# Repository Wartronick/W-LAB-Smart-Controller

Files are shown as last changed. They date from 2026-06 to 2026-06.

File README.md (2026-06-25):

# W-LAB Smart Controller ⚡

A fully integrated, 3D-printed, open-source smart lab automation controller based on the ESP32.

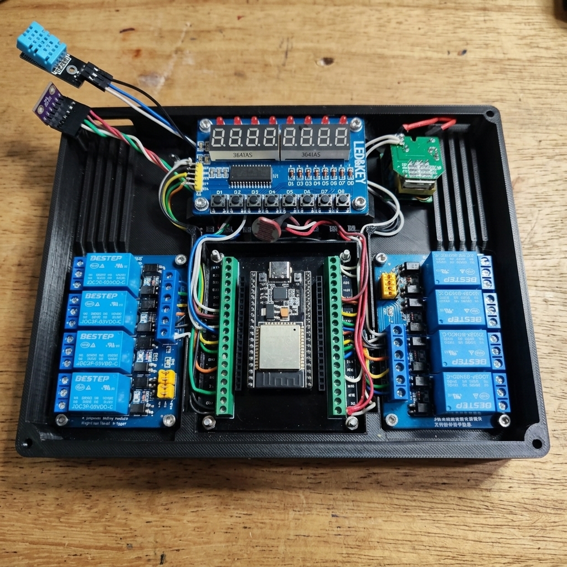
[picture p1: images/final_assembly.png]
Final Assembly


This project transforms an ESP32 into a central command hub for an automation lab (or any workshop), bringing physical controls, sensor fusion, and cloud capabilities into a single beautifully 3D-printed case.

## 📱 Cloud, UI & Voice Control

### ESP RainMaker App
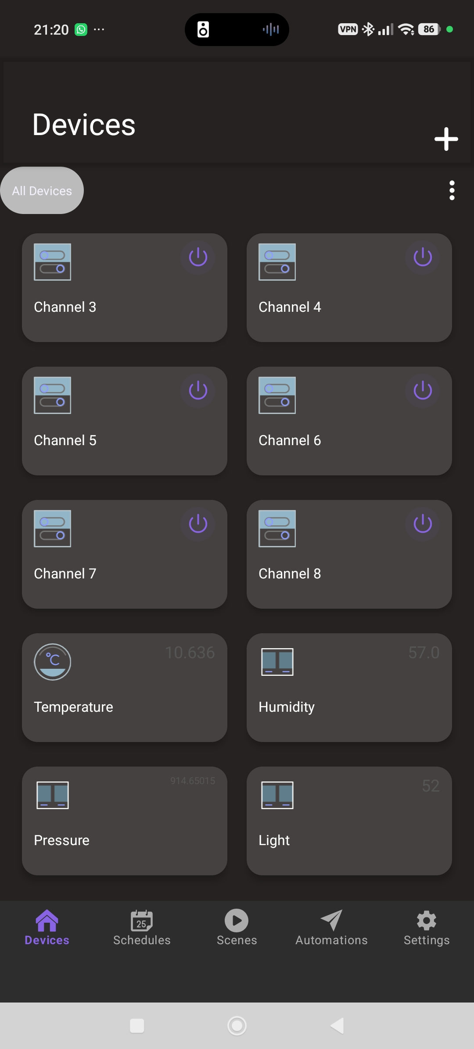
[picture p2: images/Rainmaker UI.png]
RainMaker UI

The system leverages ESP RainMaker for an instant, out-of-the-box mobile dashboard without any backend coding. It exposes all 8 relay channels and live sensor metrics.

### Google Home & Voice Commands
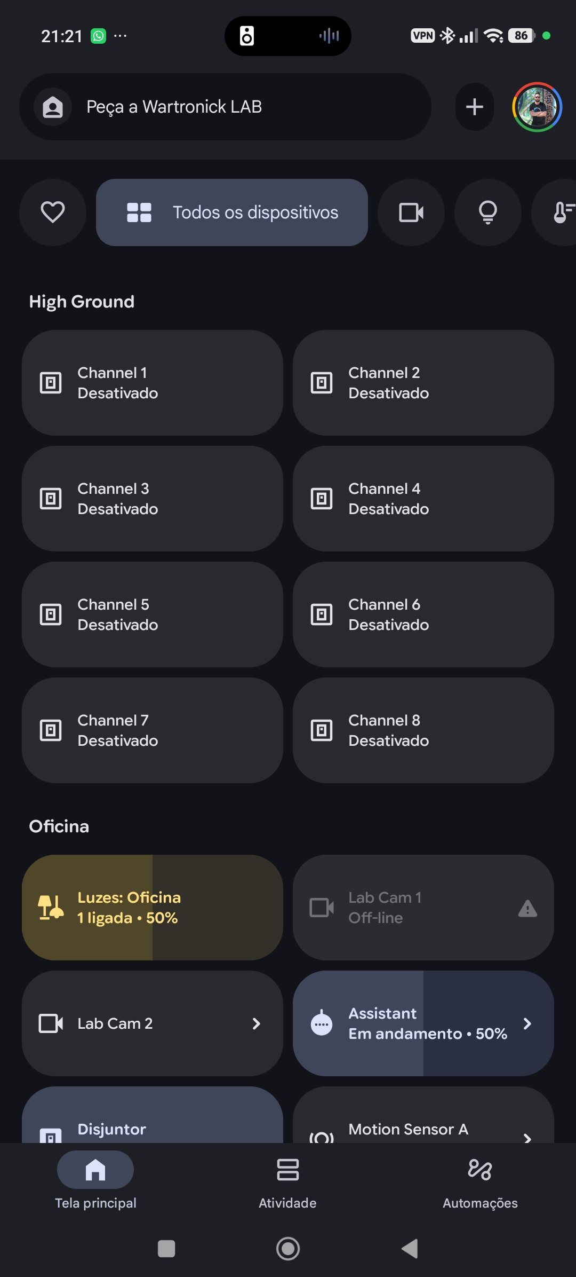
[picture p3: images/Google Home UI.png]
Google Home UI

By securely linking your RainMaker account to Google Home (or Amazon Alexa), the controller seamlessly translates into native smart home devices. You can control the lab instantly using natural voice commands:
* *"Hey Google, turn on Channel 1"* (or whatever custom name you assign to the relay, e.g., *"turn on Soldering Iron"*).
* *"Hey Google, what's the Temperature in the Lab?"*

## 🚀 Features

*   **8-Channel Relay Control:** Independently control up to 8 high-voltage/high-current devices via physical buttons, RainMaker App, Google Home, or MQTT.
*   **TM1638 Control Panel:** Features a retro-industrial 7-segment display that acts as a "Carousel", rotating through live sensor data (`t`, `H`, `P`, `L`) every 3 seconds. The 8 buttons on the panel act as physical overrides for the 8 relays.
*   **Sensor Fusion (BMP280 + DHT11):** Calculates a highly accurate "Official Temperature" using a weighted average (80% BMP280, 20% DHT11). It also records Relative Humidity and Atmospheric Pressure.
*   **Luminosity Tracking (LDR):** A self-calibrated LDR circuit tracks ambient light from 0% (total darkness) to 100% (bright light).
*   **Parasitic Power Architecture:** Due to extreme pin constraints, the sensors are powered directly by ESP32 GPIO pins acting as fake 3.3V and GND rails.

## 🗜️ Hardware & CAD

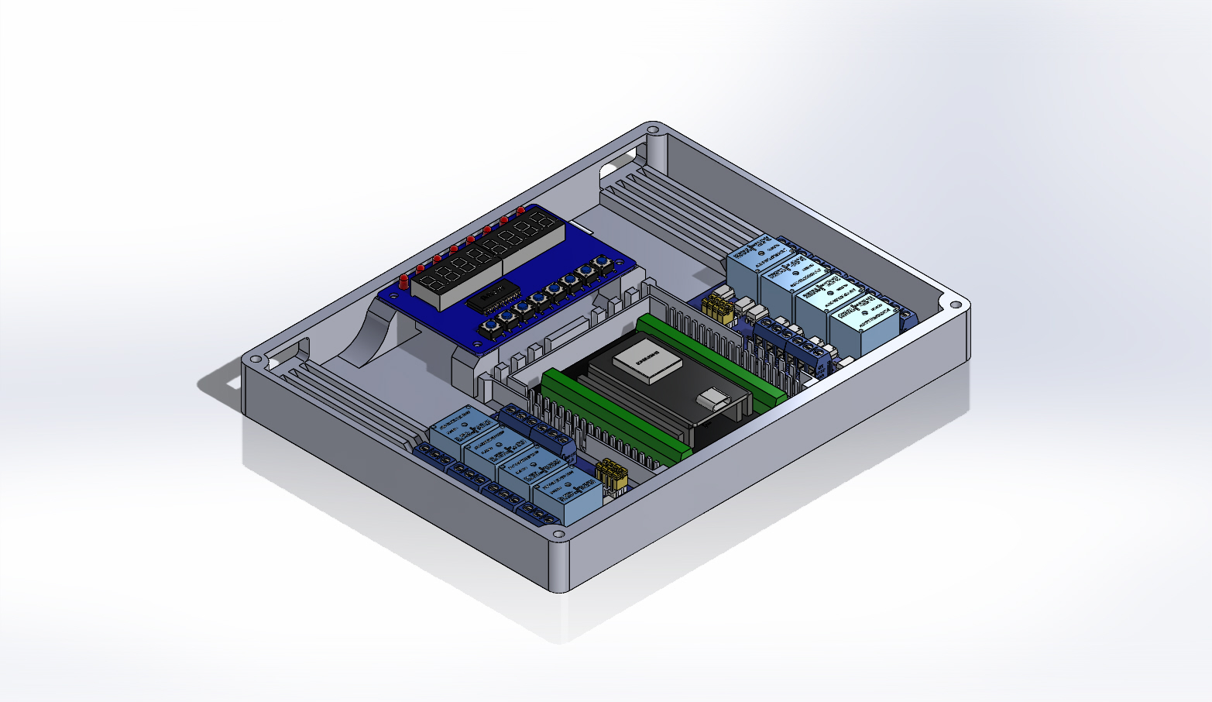
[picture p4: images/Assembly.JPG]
CAD Assembly


The `/cad` directory contains the full SolidWorks assembly (`.SLDASM`, `.SLDPRT`) and ready-to-print `Box.STL` files. 

The custom 3D printed case features:
- Central mounting for an ESP32 DevKit V1 with screw-terminal breakout boards.
- Symmetric dual 4-channel relay mounts.
- Custom wire routing channels to keep high-voltage and low-voltage lines organized.
- Top mounting for the TM1638 display and LDR sensor.

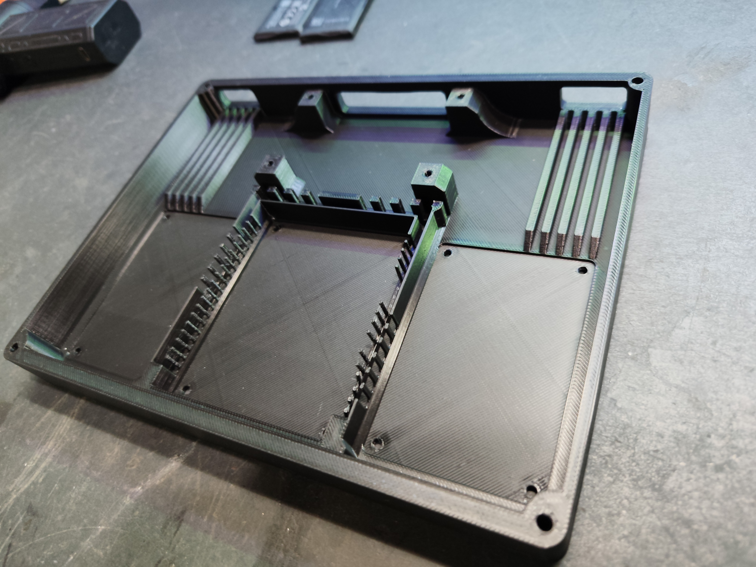
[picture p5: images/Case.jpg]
3D Printed Case

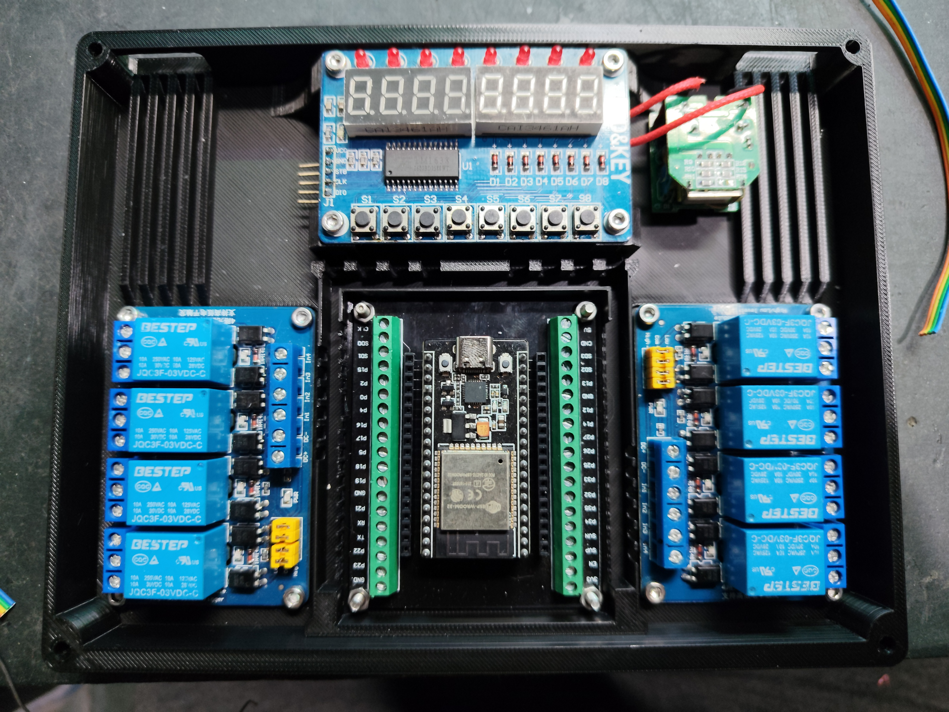
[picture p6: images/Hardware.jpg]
Internal Hardware


## 🔌 Pinout & Wiring

**Warning on Boot Pins:** Do not use GPIO 0, 2, or 15 for sensors, as they are strapping pins and will cause boot failures.

### Relays (8 Channels)
*   Relay 1 to 8: `GPIO 13`, `12`, `14`, `27`, `26`, `25`, `33`, `32`

### TM1638 Display
*   STB: `GPIO 4`, CLK: `GPIO 18`, DIO: `GPIO 19`

### Sensors (I2C & Analog)
*   **I2C SDA (BMP280):** `GPIO 21` | **I2C SCL (BMP280):** `GPIO 22`
*   **LDR Signal:** `GPIO 34` (ADC1) | **LDR VCC & GND:** Physical pins

### Parasitic Power Rails (The "Hack")
*   **DHT11 Signal:** `GPIO 5`
*   **Shared Sensor GND:** `GPIO 16` (Driven LOW in setup)
*   **DHT11 VCC:** `GPIO 17` (Driven HIGH in setup)

## 📡 MQTT Integration (Home Assistant)

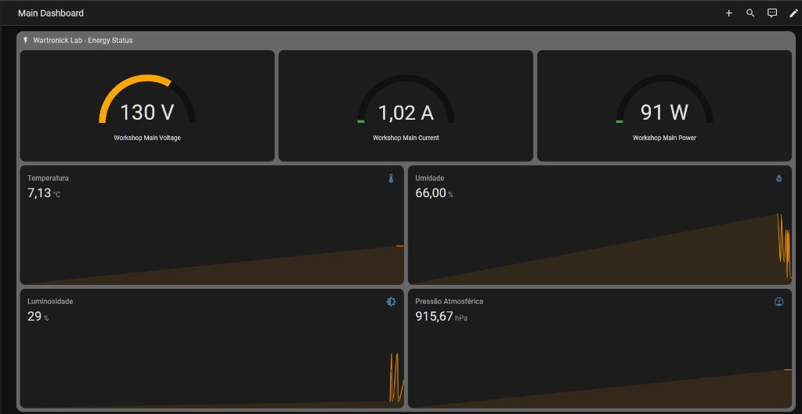
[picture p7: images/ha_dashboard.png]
Home Assistant Dashboard

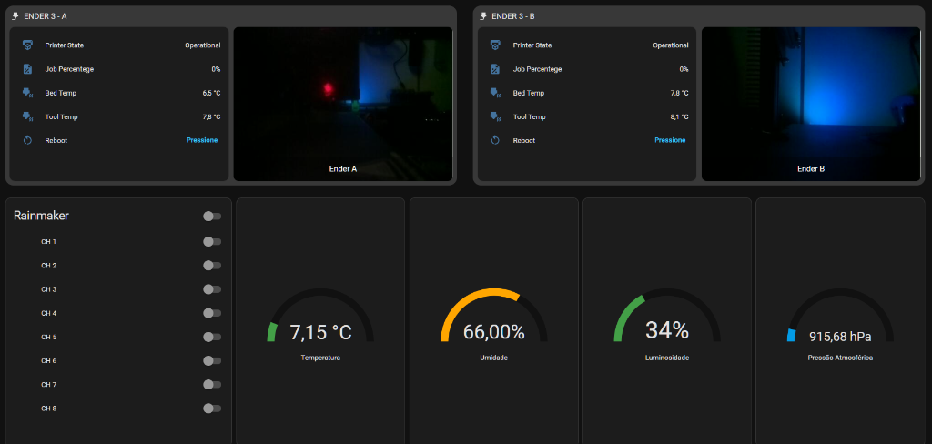
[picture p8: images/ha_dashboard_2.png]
Home Assistant Dashboard Printers


While RainMaker provides external cloud access, the W-LAB Smart Controller also features a fully independent **Local MQTT Client**. This ensures absolute reliability, privacy, and ultra-low latency integration with systems like **Home Assistant** or Node-RED, bypassing the cloud entirely for your local automations.

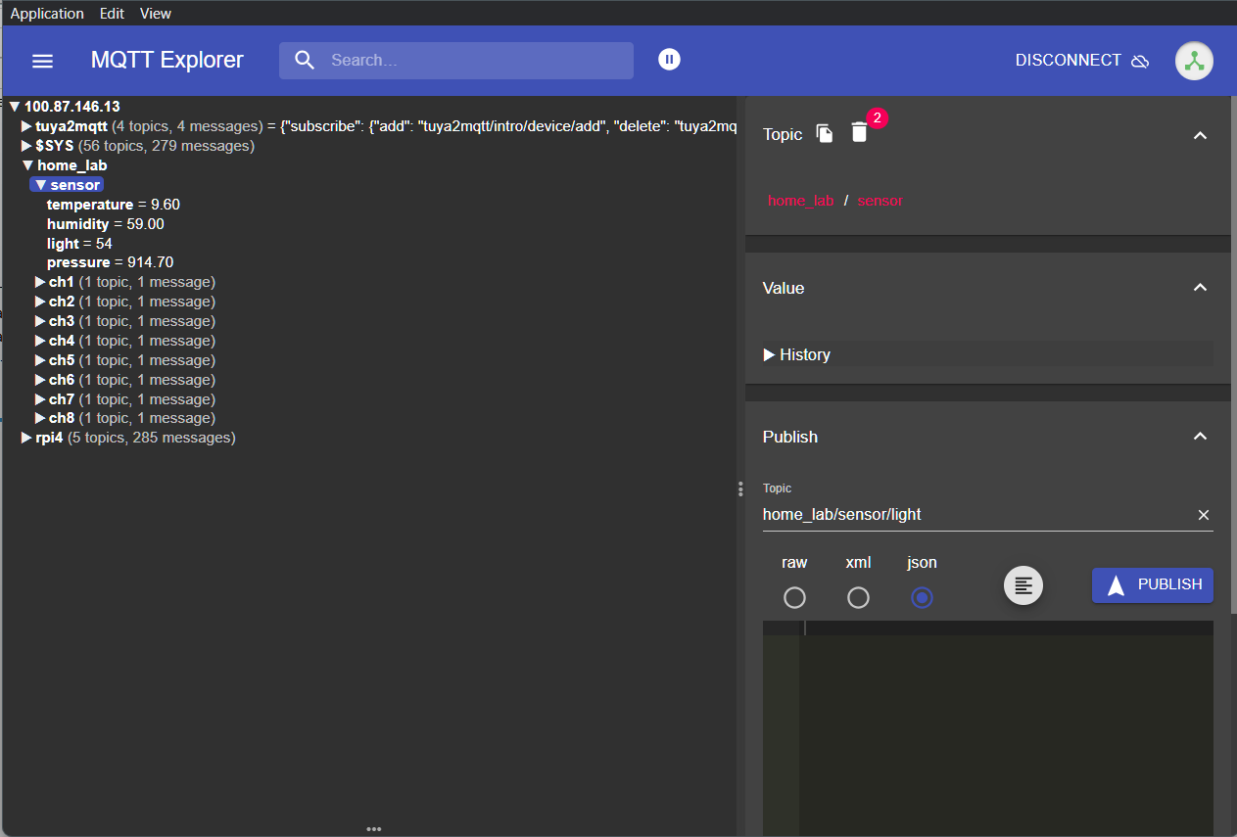
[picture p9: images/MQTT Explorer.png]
MQTT Explorer


The controller publishes live, staggered telemetry data to the following topics:
*   `home_lab/sensor/temperature`
*   `home_lab/sensor/humidity`
*   `home_lab/sensor/pressure`
*   `home_lab/sensor/light`

It also subscribes to local command topics allowing external systems to control the relays:
*   `home_lab/ch[1-8]/set` (Payload: `ON`, `OFF`, `TOGGLE`)

And publishes its state feedback so Home Assistant switches stay perfectly in sync:
*   `home_lab/ch[1-8]/status` (Payload: `ON`, `OFF`)

> **Note for Home Assistant users:** We have provided a ready-to-use `home_assistant.yaml` file in this repository. Simply copy its contents into your HA `configuration.yaml` to instantly add all 4 sensors and 8 relays to your dashboard!

## 🛠️ Usage

1. Open `src/Rainmaker_Final/Rainmaker_Final.ino` using the Arduino IDE.
2. Update your local Wi-Fi and MQTT Broker credentials in the source code.
3. Flash the code to the ESP32 (Requires ESP32 core v2.0.x).
4. Link your account to Google Home for seamless voice control.
5. Mount it on your wall and enjoy the clicking sounds of automation!

## 📝 License
This project is licensed under the MIT License - see the `LICENSE` file for details.

## 🤝 Contributing
Contributions are welcome! Please feel free to submit a Pull Request.

## 📧 Contact
**Author:** MSc. Alexandre Domingues  
**GitHub:** [@Wartronick](https://github.com/Wartronick)  
**Email:** alexandre.mecatronica@hotmail.com

## 🙏 Acknowledgments
*   **UTFPR** and **LARA Laboratory** for providing resources and support.
*   The open-source Maker and Home Assistant communities for their excellent tools and inspiration.

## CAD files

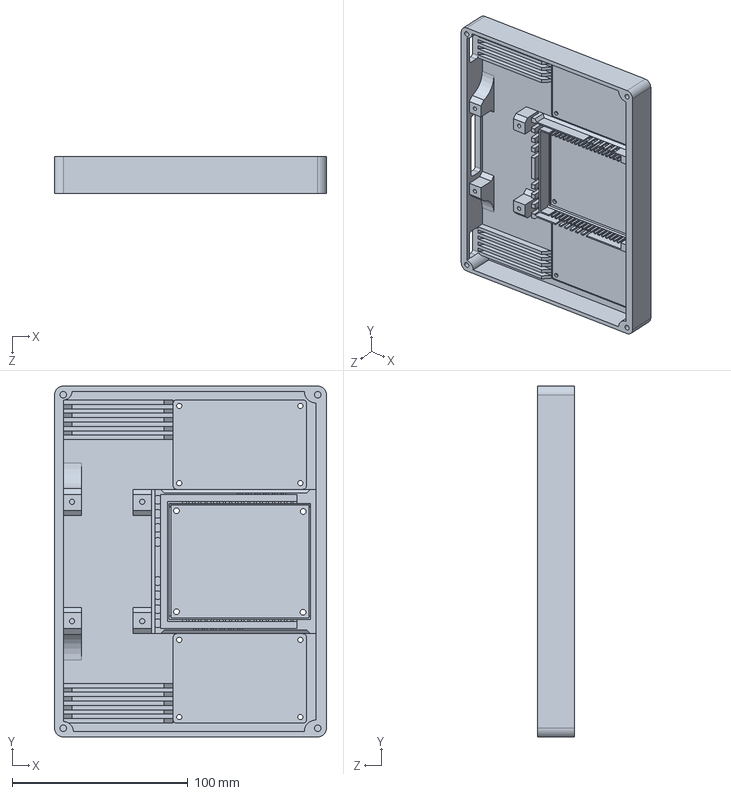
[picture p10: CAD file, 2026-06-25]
cad/Box.SLDPRT
155.0 x 200.0 x 21.0 mm

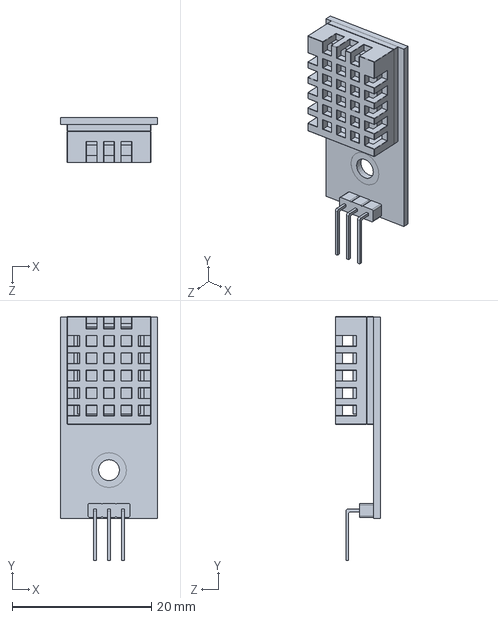
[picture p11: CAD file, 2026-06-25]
cad/DHT11.SLDPRT
14.0 x 35.0 x 6.50 mm

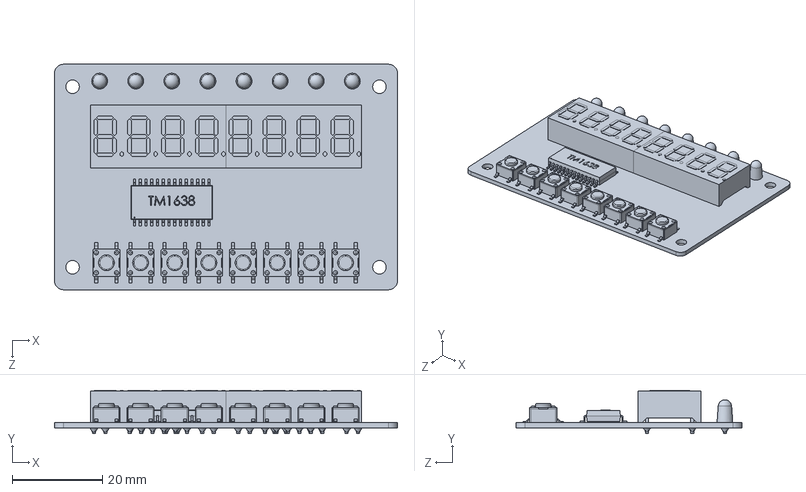
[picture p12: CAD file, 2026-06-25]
cad/Led + Key.SLDPRT
76.0 x 9.60 x 50.0 mm

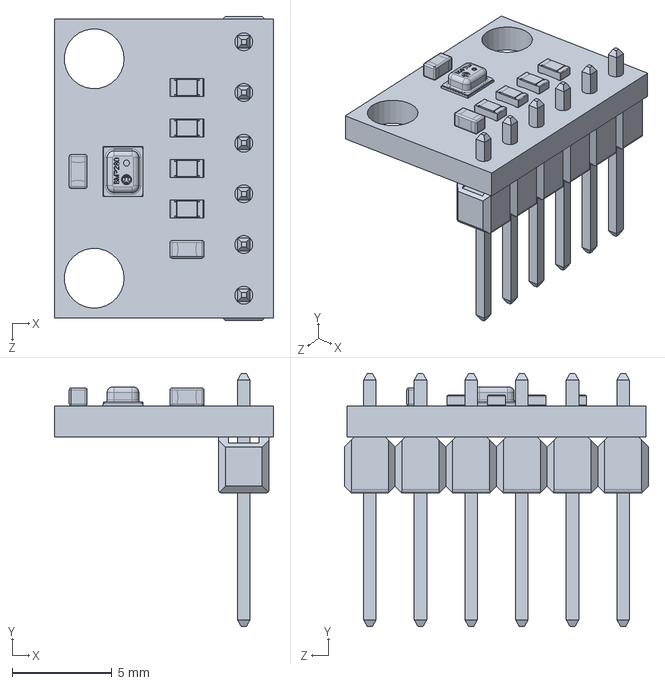
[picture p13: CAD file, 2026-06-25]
cad/BMP280.SLDPRT
11.0 x 12.7 x 15.2 mm

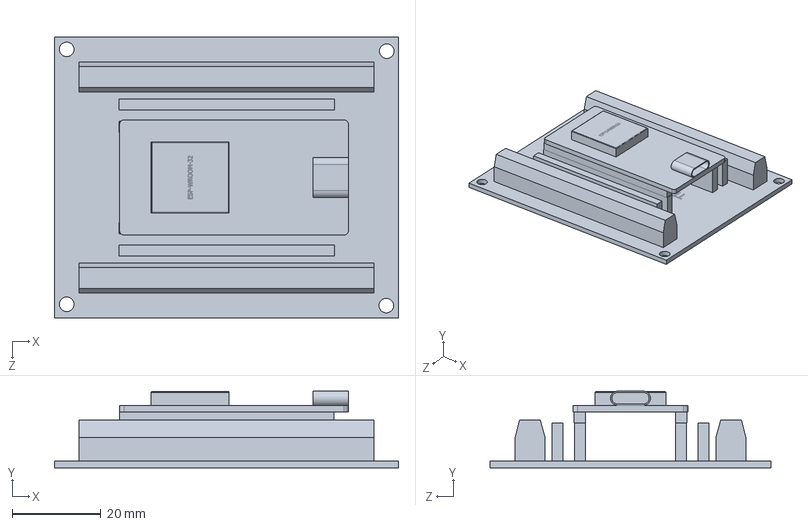
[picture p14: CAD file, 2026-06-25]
cad/Terminal Adapter.SLDPRT
77.6 x 17.3 x 63.3 mm

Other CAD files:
cad/Box.STL

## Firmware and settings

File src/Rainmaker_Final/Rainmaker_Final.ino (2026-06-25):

#include "RMaker.h"
#include "WiFi.h"
#include "WiFiProv.h"
#include <PubSubClient.h>
#include <TM1638plus.h>
#include <Wire.h>
#include <Adafruit_Sensor.h>
#include <Adafruit_BMP280.h>
#include <DHT.h>
#include <esp_system.h>
#include <esp_rmaker_factory.h>
#include <esp_partition.h>

// BLE Provisioning Configuration (RainMaker)
const char *service_name = "Wartronick_esp";
const char *pop = "Engenharia";

// App provisioning is disabled due to BLE Payload limits with 10+ devices.
// The board connects directly to the network.

// Local MQTT Broker Configuration
const char* mqtt_server = "192.168.X.XXX"; // CHANGE THIS: Your Raspberry Pi / Home Assistant IP
const int mqtt_port = 1883;

WiFiClient espClient;
PubSubClient mqtt_client(espClient);
uint32_t lastReconnectAttempt = 0;

// TM1638 Initialization (STB, CLK, DIO, true to prevent read desync on Core 2.x)
TM1638plus tm(18, 19, 21, true);
uint8_t lastButtons = 0;

// 7-segment display control variables
unsigned long displayTimer = 0;
bool showingStatus = false;

// Sequential definition of the 8 relay pins
uint8_t channelPins[] = {13, 12, 14, 27, 26, 25, 33, 32};
bool channelStates[8] = {false};

static Switch *my_switches[8];
String channelNames[8]; // Array to persistently store channel names

// --- PIN DEFINITIONS ---
#define I2C_SDA 4
#define I2C_SCL 22

// Sensores
#define DHT_VCC_PIN 17
#define DHT_PIN 5
#define DHT_GND_PIN 16
#define LDR_PIN 34 // ADC1
// DHT Type
Adafruit_BMP280 bmp;
bool bmp_status = false;

#define DHTPIN 5
#define DHTTYPE DHT11
DHT dht(DHTPIN, DHTTYPE);

unsigned long lastSensorRead = 0;

// Sensor Data Cache for TM1638 Display
float cache_bmp_t = 0, cache_bmp_p = 0;
float cache_dht_t = 0, cache_dht_h = 0;
int cache_ldr = 0;
float official_temp = 0; // Sensor Fusion (Weighted Average)

static TemperatureSensor *temp_sensor; // Primary for Google Home
static Device *hum_sensor;
static Device *press_sensor;
static Device *light_sensor;

// --- CENTRAL UPDATE AND SYNCHRONIZATION FUNCTION ---
void updateChannel(int id, bool state, bool updateApp, bool updateMQTT) {
  if (id < 0 || id >= 8) return;

  channelStates[id] = state;
  digitalWrite(channelPins[id], state ? HIGH : LOW);

  // Update the corresponding physical LED on the TM1638 panel
  tm.setLED(id, state ? 1 : 0);

  // Update the 7-segment display text dynamically (String avoids buffer overflow crash)
  String text = "CH " + String(id + 1) + (state ? " ON" : " OFF");
  while (text.length() < 8) text += " ";
  tm.displayText(text.c_str());

  displayTimer = millis();
  showingStatus = true;

  Serial.printf("[RELAY] Channel %d changed to %s\n", id + 1, state ? "ON" : "OFF");

  // Synchronize and update the RainMaker mobile app
  if (updateApp) {
    my_switches[id]->updateAndReportParam(ESP_RMAKER_DEF_POWER_NAME, state);
  }

  // Synchronize and publish the new state to the local MQTT Broker
  if (updateMQTT && mqtt_client.connected()) {
    String topic = "home_lab/ch" + String(id + 1) + "/status";
    if (!mqtt_client.publish(topic.c_str(), state ? "ON" : "OFF")) {
       Serial.println("[MQTT] ERROR: Failed to publish relay state!");
    }
  }
}

// --- MQTT RECEIVED COMMANDS CALLBACK ---
void mqtt_callback(char* topic, byte* payload, unsigned int length) {
  String msg;
  for (int i = 0; i < length; i++) msg += (char)payload[i];

  String topicStr(topic);
  for (int i = 0; i < 8; i++) {
    String expectedTopic = "home_lab/ch" + String(i + 1) + "/set";
    if (topicStr == expectedTopic) {
      if (msg == "ON") updateChannel(i, true, true, false);
      else if (msg == "OFF") updateChannel(i, false, true, false);
      else if (msg == "TOGGLE") updateChannel(i, !channelStates[i], true, true);
    }
  }
}

// --- AUTOMATIC AND NON-BLOCKING MQTT RECONNECTION ---
void reconnectMQTT() {
  if (WiFi.status() == WL_CONNECTED && (millis() - lastReconnectAttempt > 5000)) {
    lastReconnectAttempt = millis();
    String clientId = "ESP32_Lab";
    
    if (mqtt_client.connect(clientId.c_str())) {
      mqtt_client.subscribe("home_lab/#"); // O curinga '#' é permitido. O '+' junto com texto (ch+) é proibido pelo MQTT!
      Serial.println("[MQTT] Connected to Local Broker");
    }
  }
}

// --- RAINMAKER APP RECEIVED COMMANDS CALLBACK ---
void write_callback(Device *device, Param *param, const param_val_t val, void *priv_data, write_ctx_t *ctx) {
  const char *device_name = device->getDeviceName();
  if (strcmp(param->getParamName(), "Power") == 0) {
    for (int i = 0; i < 8; i++) {
      if (strcmp(device_name, channelNames[i].c_str()) == 0) {
        updateChannel(i, val.val.b, false, true);
        param->updateAndReport(val);
      }
    }
  }
}

void setup() {
  // Spoof MAC Address (Bypass Espressif cloud chip block)
  uint8_t fake_mac[6] = {0x24, 0x0A, 0xC4, 0x11, 0x22, 0x33};
  esp_base_mac_addr_set(fake_mac);

  Serial.begin(115200);
  delay(1000); // Additional delay to stabilize voltage

  Serial.println("\n[SYSTEM] Booting ESP32 Control Hub (Spoofed MAC)...");

  // Relay output pins configuration BEFORE any consumption
  for (int i = 0; i < 8; i++) {
    pinMode(channelPins[i], OUTPUT);
    digitalWrite(channelPins[i], LOW); // Starts off
  }
  
  pinMode(LDR_PIN, INPUT);

  // TM1638 display initialization and configuration
  tm.displayBegin();
  tm.brightness(3);
  tm.reset();
  
  // --- BOOT ANIMATION (Knight Rider style) ---
  tm.displayText("BOOTING ");
  for (int pass = 0; pass < 3; pass++) {
    for (int i = 0; i < 8; i++) {
      tm.setLED(i, 1);
      delay(20);
      tm.setLED(i, 0);
    }
    for (int i = 6; i >= 1; i--) {
      tm.setLED(i, 1);
      delay(20);
      tm.setLED(i, 0);
    }
  }
  for (int flash = 0; flash < 2; flash++) {
    for (int i = 0; i < 8; i++) tm.setLED(i, 1);
    delay(150);
    for (int i = 0; i < 8; i++) tm.setLED(i, 0);
    delay(150);
  }

  // --- SEQUENTIAL PHYSICAL RELAY TEST ---
  tm.displayText("TEST Ch");
  Serial.println("[SYSTEM] Running physical relay test...");
  for (int i = 0; i < 8; i++) {
    digitalWrite(channelPins[i], HIGH); // Turn relay ON
    tm.setLED(i, 1);
    delay(150); // Keep ON for 150ms
    digitalWrite(channelPins[i], LOW);  // Turn relay OFF
    tm.setLED(i, 0);
  }
  
  tm.displayText("LAB CTRL"); // Final default screen

  // --- SENSOR INIT ---
  // Turn on parasitic power plant FIRST! (BMP280 relies on GND from pin 16)
  pinMode(DHT_VCC_PIN, OUTPUT);
  pinMode(DHT_GND_PIN, OUTPUT);
  
  digitalWrite(DHT_GND_PIN, LOW);  // Create shared Ground (DHT and BMP)
  digitalWrite(DHT_VCC_PIN, HIGH); // Create 3.3V for DHT
  delay(1500); // Give chips time to wake up before I2C/OneWire communication
  
  Wire.begin(I2C_SDA, I2C_SCL);
  bmp_status = bmp.begin(0x76); 
  if (!bmp_status) bmp_status = bmp.begin(0x77); // Try alternative default address
  Serial.println(bmp_status ? "[SENSOR] BMP280 initialized successfully." : "[SENSOR] Failed to find BMP280 sensor!");
  
  dht.begin();
  Serial.println("[SENSOR] DHT11 initialized.");

  mqtt_client.setServer(mqtt_server, mqtt_port);
  mqtt_client.setCallback(mqtt_callback);
  mqtt_client.setBufferSize(1024); // Aumentado para evitar que mensagens retidas do broker derrubem a conexão

  // Physically verify where the secret partition is located on the board
  const esp_partition_t *fctry_part = esp_partition_find_first(ESP_PARTITION_TYPE_DATA, ESP_PARTITION_SUBTYPE_DATA_NVS, "fctry");
  if (fctry_part != NULL) {
      Serial.printf("\n[DEBUG] fctry partition FOUND at address: 0x%x\n", fctry_part->address);
  } else {
      Serial.println("\n[DEBUG] WARNING: fctry partition NOT FOUND!\n");
  }

  // Initialize the "fctry" partition
  esp_err_t err = esp_rmaker_factory_init();
  if (err != ESP_OK) {
      Serial.printf("[DEBUG] Failed to load certificates from fctry partition! Error: %d\n", err);
  } else {
      Serial.println("[DEBUG] Certificates loaded from fctry partition successfully!");
  }

  // Node and Devices initialization in the RainMaker ecosystem
  Node my_node = RMaker.initNode("Wartronick Hub");
  for (int i = 0; i < 8; i++) {
    channelNames[i] = "Channel " + String(i + 1);
    my_switches[i] = new Switch(channelNames[i].c_str(), &channelPins[i]);
    my_switches[i]->addCb(write_callback);
    my_node.addDevice(*my_switches[i]);
    delay(50);
  }
  
  // --- RAINMAKER SENSOR DEVICES ---
  // 1. Temperature Device (Standard type for Google Home compatibility)
  temp_sensor = new TemperatureSensor("Temperature");
  my_node.addDevice(*temp_sensor);
  
  // 2. Humidity Device
  hum_sensor = new Device("Humidity", "esp.device.other");
  Param hum_param("Humidity", "custom.param.humidity", value(0.0f), PROP_FLAG_READ);
  hum_param.addUIType(ESP_RMAKER_UI_TEXT);
  hum_sensor->addParam(hum_param);
  hum_sensor->assignPrimaryParam((param_handle_t *)hum_param.getParamHandle());
  my_node.addDevice(*hum_sensor);
  
  // 3. Pressure Device
  press_sensor = new Device("Pressure", "esp.device.other");
  Param press_param("Pressure", "custom.param.pressure", value(0.0f), PROP_FLAG_READ);
  press_param.addUIType(ESP_RMAKER_UI_TEXT);
  press_sensor->addParam(press_param);
  press_sensor->assignPrimaryParam((param_handle_t *)press_param.getParamHandle());
  my_node.addDevice(*press_sensor);
  
  // 4. Light Device
  light_sensor = new Device("Light", "esp.device.other");
  Param light_param("Brightness", "custom.param.light", value(0), PROP_FLAG_READ);
  light_param.addUIType(ESP_RMAKER_UI_TEXT);
  light_sensor->addParam(light_param);
  light_sensor->assignPrimaryParam((param_handle_t *)light_param.getParamHandle());
  my_node.addDevice(*light_sensor);

  // Secondary services disabled to save memory and avoid node registration crashes
  // RMaker.enableOTA(OTA_USING_PARAMS);
  // RMaker.enableTZService();
  
  // Direct Wi-Fi Connection (Bypassing BLE Payload Bug)
  Serial.println("\n[SYSTEM] Connecting to Wi-Fi...");
  WiFi.mode(WIFI_STA);
  WiFi.begin("YOUR_WIFI_SSID", "YOUR_WIFI_PASSWORD"); // CHANGE THIS
  
  while (WiFi.status() != WL_CONNECTED) {
    delay(500);
    Serial.print(".");
  }
  
  Serial.println("\n[SYSTEM] Wi-Fi Connected Successfully!");
  
  // Start RainMaker
  RMaker.start();
}

void loop() {
  // 1. Network processing and maintenance (Local MQTT)
  if (!mqtt_client.connected()) {
    int currentState = mqtt_client.state();
    if (millis() - lastReconnectAttempt > 4900) {
       // Print the error right before reconnecting to avoid flooding the serial
       Serial.printf("\n[MQTT] Connection Dropped! PubSubClient Error Code: %d\n", currentState);
    }
    reconnectMQTT();
  } else {
    mqtt_client.loop();
  }

  // 2. Panel buttons scan
  static unsigned long lastScan = 0;
  if (millis() - lastScan > 50) { 
    uint8_t raw_buttons = tm.readButtons();
    
    // Ignore only the error noise (255)
    if (raw_buttons != 255 && raw_buttons != lastButtons) {
      for (int i = 0; i < 8; i++) {
        if ((raw_buttons & (1 << i)) && !(lastButtons & (1 << i))) {
           updateChannel(i, !channelStates[i], true, true);
        }
      }
      lastButtons = raw_buttons;
    }
    lastScan = millis();
  }

  // 3. Display Rotation Logic (Carousel)
  if (showingStatus) {
    if (millis() - displayTimer > 2000) {
      showingStatus = false;
      displayTimer = millis(); // Reset timer for the carousel
    }
  } else {
    // Rotate sensor data every 3 seconds
    static int displayState = 0;
    if (millis() - displayTimer > 3000) {
      displayTimer = millis();
      char buffer[9]; // 8 characters + null terminator
      
      if (displayState == 0) {
        snprintf(buffer, sizeof(buffer), "t   %-4.1f", official_temp); // "t   24.5"
      } else if (displayState == 1) {
        snprintf(buffer, sizeof(buffer), "H   %-4d", (int)cache_dht_h); // "H   45  "
      } else if (displayState == 2) {
        snprintf(buffer, sizeof(buffer), "P   %-4d", (int)cache_bmp_p); // "P   913 "
      } else if (displayState == 3) {
        snprintf(buffer, sizeof(buffer), "L   %-4d", cache_ldr); // "L   100 "
      }
      
      tm.displayText(buffer);
      displayState = (displayState + 1) % 4; // Move to next sensor
    }
  }

  // 4. Sensor Reading (Staggered to avoid RainMaker MQTT Budget limits)
  static unsigned long lastSensorRead = 0;
  static int sensorState = 0; // 0=BMP, 1=DHT, 2=LDR

  if (millis() - lastSensorRead > 3000) { // Every 3 seconds, reads one sensor
    lastSensorRead = millis();
    
    if (sensorState == 0) {
      // BMP280 Reading
      if (bmp_status) {
        float t_bmp = bmp.readTemperature();
        float p_bmp = bmp.readPressure() / 100.0F;
        cache_bmp_t = t_bmp;
        cache_bmp_p = p_bmp;
        Serial.printf("[SENSOR] BMP280 -> Temp: %.1f C | Press: %.1f hPa\n", t_bmp, p_bmp);
        
        press_sensor->updateAndReportParam("Pressure", p_bmp);
        
        if (mqtt_client.connected()) {
          if (!mqtt_client.publish("home_lab/sensor/pressure", String(p_bmp).c_str())) Serial.println("[MQTT] ERROR: Publish pressure failed!");
        }
      }
      sensorState = 1;
    } 
    else if (sensorState == 1) {
      // DHT11 Reading
      float h_dht = dht.readHumidity();
      float t_dht = dht.readTemperature();
      if (!isnan(h_dht) && !isnan(t_dht)) {
        cache_dht_h = h_dht;
        cache_dht_t = t_dht;
        Serial.printf("[SENSOR] DHT11 -> Temp: %.1f C | Humidity: %.1f %%\n", t_dht, h_dht);
        
        // Sensor Fusion (Weighted Average: 80% BMP, 20% DHT)
        if (cache_bmp_t > 0) {
          official_temp = (cache_bmp_t * 0.8) + (t_dht * 0.2);
        } else {
          official_temp = t_dht; // Fallback if BMP fails
        }
        Serial.printf("[SENSOR] FUSION -> Official Temp: %.1f C\n", official_temp);
        
        temp_sensor->updateAndReportParam("Temperature", official_temp);
        hum_sensor->updateAndReportParam("Humidity", h_dht);
        
        if (mqtt_client.connected()) {
          if (!mqtt_client.publish("home_lab/sensor/temperature", String(official_temp).c_str())) Serial.println("[MQTT] ERROR: Publish temperature failed!");
          if (!mqtt_client.publish("home_lab/sensor/humidity", String(h_dht).c_str())) Serial.println("[MQTT] ERROR: Publish humidity failed!");
        }
      } else {
        Serial.println("[SENSOR] DHT11 -> Read failed! Wiring or warm-up issue.");
      }
      sensorState = 2;
    } 
    else if (sensorState == 2) {
      // LDR Reading (Mapped to 0-100% with Calibration)
      int raw_ldr = analogRead(LDR_PIN);
      
      // LDR Calibration: Total darkness is approx 800 raw value, bright light is 0
      int raw_constrained = raw_ldr;
      if (raw_constrained > 800) raw_constrained = 800;
      
      int ldr_percent = map(raw_constrained, 800, 0, 0, 100);
      if (ldr_percent < 0) ldr_percent = 0;
      if (ldr_percent > 100) ldr_percent = 100;
      
      cache_ldr = ldr_percent;
      Serial.printf("[SENSOR] LDR -> Raw: %d | Brightness: %d %%\n", raw_ldr, ldr_percent);
      
      light_sensor->updateAndReportParam("Brightness", ldr_percent);
      
      if (mqtt_client.connected()) {
        if (!mqtt_client.publish("home_lab/sensor/light", String(ldr_percent).c_str())) Serial.println("[MQTT] ERROR: Publish light failed!");
      }
      sensorState = 0;
    }
  }

  // 5. Factory Reset safety logic (BOOT Button / GPIO 0)
  if (digitalRead(0) == LOW) {
    delay(100);
    int startTime = millis();
    while (digitalRead(0) == LOW) {
      delay(50);
      mqtt_client.loop();
    }
    if ((millis() - startTime) > 5000) {
      Serial.println("[SYSTEM] Factory Reset Triggered!");
      RMakerFactoryReset(2);
    }
  }
}

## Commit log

2026-06-25 Enhance README with voice control and relay details
    Updated README to include voice control features and clarified relay control methods.
2026-06-25 W-LAB Smart Controller V1.0
    Full release including CAD files, RainMaker ESP32 firmware, Local MQTT integration for Home Assistant, and final assembly dashboard images.
2026-06-25 Update README with final Home Assistant dashboards
    Added the final Home Assistant dashboard images featuring the 3D printer integrations and updated the MQTT configuration details.
